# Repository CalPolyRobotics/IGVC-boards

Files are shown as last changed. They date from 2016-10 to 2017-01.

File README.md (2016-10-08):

# IGVC-boards
IGVC schematic and board files

.gitignore is set to only allow uploads of .sch, .brd, and .lib files.

Do not modify folders with "Final" in the name.

Pro tips:

1. Clone this repository to your computer. You need git.

2. In Eagle, go to Options > Directories.

3. Click in the "Projects" text field and then the "Browse" button to choose a directory.

4. Select the "IGVC-boards" directory that you cloned from git.

5. Click "OK" and you should see the directory in the "Projects" list in Eagle Control Panel.

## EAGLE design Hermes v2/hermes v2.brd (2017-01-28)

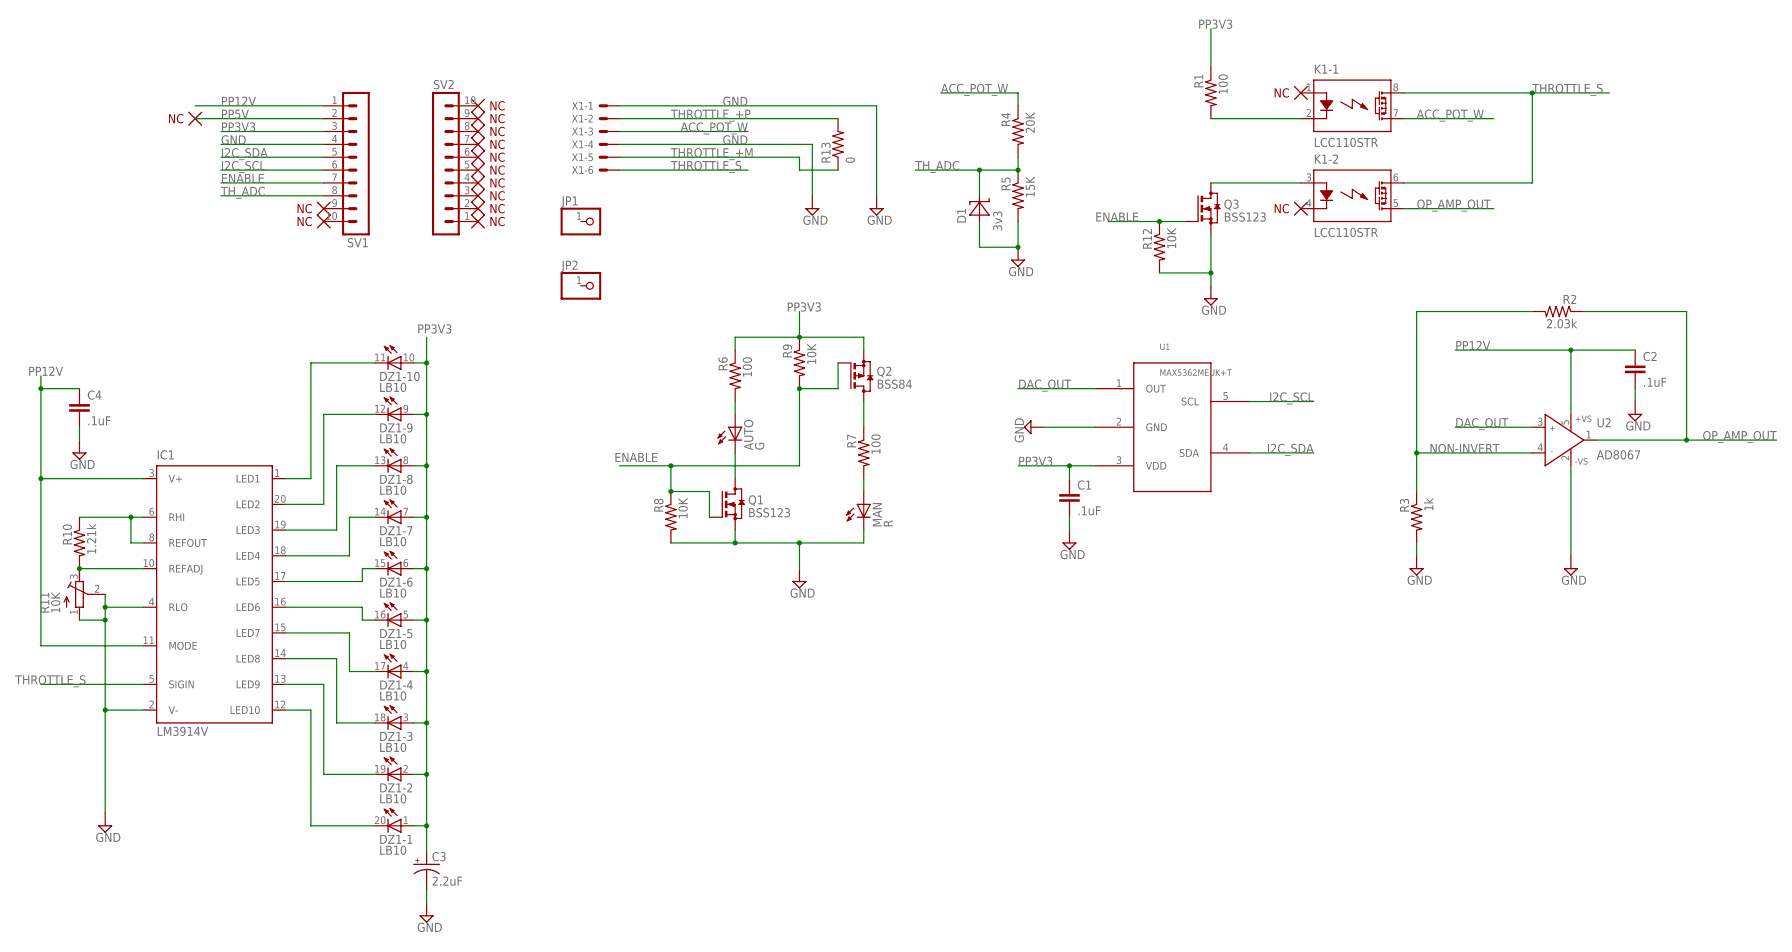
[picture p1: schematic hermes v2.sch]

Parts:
AUTO: G; LED_SML0603
C1, C2, C4: .1uF; C0402
C3: 2.2uF; SMC_A; DIGI 478-3119-2-ND
D1: 3v3; SOD323_ST
DZ1: LB10
IC1: LM3914V; PLCC20S
JP1, JP2: PINHD-1X1; 1X01
K1: LCC110STR; DIL08SMD
MAN: R; LED_SML0603
Q1, Q3: BSS123; SOT23
Q2: BSS84; SOT23
R1, R6, R7: 100; R0603
R2: 2.03k; R0603
R3: 1k; R0603
R4: 20K; R0603
R5: 15K; R0603
R8, R9, R12: 10K; R0603
R10: 1.21k; R0603
R11: 10K; RTRIM5X; DIGI 490-2678-1-ND
R13: 0; R0402
SV1, SV2: MA10-1
U1: DAC; SOT23-5
U2: AD8067; SOT23-5; DIGI 497-13051-1-ND
X1: 22-23-2061

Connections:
ACC_POT_W: K1.7 (D2), R4.1, X1.3
CONTROL_+: K1.2 (K), R1.2
CONTROL_-: K1.3 (A), Q3.3 (D)
DAC_OUT: U1.1 (OUT), U2.3 (IN+)
ENABLE: Q1.1 (G), Q2.1 (G), Q3.1 (G), R8.1, R9.2, R12.1, SV1.7
GND: C1.2, C2.2, C3.-, C4.2, D1.A, IC1.2 (V-), IC1.4 (RLO), MAN.C, Q1.2 (S), Q3.2 (S), R3.2, R5.2, R8.2, R11.1 (A), R11.2 (S), R12.2, SV1.4, U1.2 (GND), U2.2 (-VS), X1.1, X1.4
I2C_SCL: SV1.6, U1.5 (SCL)
I2C_SDA: SV1.5, U1.4 (SDA)
unnamed: DZ1.11 (C), IC1.1 (LED1)
unnamed: AUTO.C, Q1.3 (D)
unnamed: MAN.A, R7.2
unnamed: AUTO.A, R6.2
unnamed: Q2.3 (D), R7.1
unnamed: DZ1.12 (C), IC1.20 (LED2)
unnamed: DZ1.13 (C), IC1.19 (LED3)
unnamed: DZ1.14 (C), IC1.18 (LED4)
unnamed: DZ1.15 (C), IC1.17 (LED5)
unnamed: DZ1.16 (C), IC1.16 (LED6)
unnamed: DZ1.17 (C), IC1.15 (LED7)
unnamed: DZ1.18 (C), IC1.14 (LED8)
unnamed: DZ1.19 (C), IC1.13 (LED9)
unnamed: DZ1.20 (C), IC1.12 (LED10)
unnamed: IC1.10 (REFADJ), R10.2, R11.3 (E)
unnamed: IC1.6 (RHI), IC1.8 (REFOUT), R10.1
NON-INVERT: R2.2, R3.1, U2.4 (IN-)
OP_AMP_OUT: K1.5 (D2), R2.1, U2.1 (OUT)
PP3V3: C1.1, C3.+, DZ1.1 (A), DZ1.2 (A), DZ1.3 (A), DZ1.4 (A), DZ1.5 (A), DZ1.6 (A), DZ1.7 (A), DZ1.8 (A), DZ1.9 (A), DZ1.10 (A), Q2.2 (S), R1.1, R6.1, R9.1, SV1.3, U1.3 (VDD)
PP5V: SV1.2
PP12V: C2.1, C4.1, IC1.3 (V+), IC1.11 (MODE), SV1.1, U2.5 (+VS)
THROTTLE_+M: R13.1, X1.5
THROTTLE_+P: R13.2, X1.2
THROTTLE_S: IC1.5 (SIGIN), K1.6 (D1), K1.8 (D1), X1.6
TH_ADC: D1.C, R4.2, R5.1, SV1.8

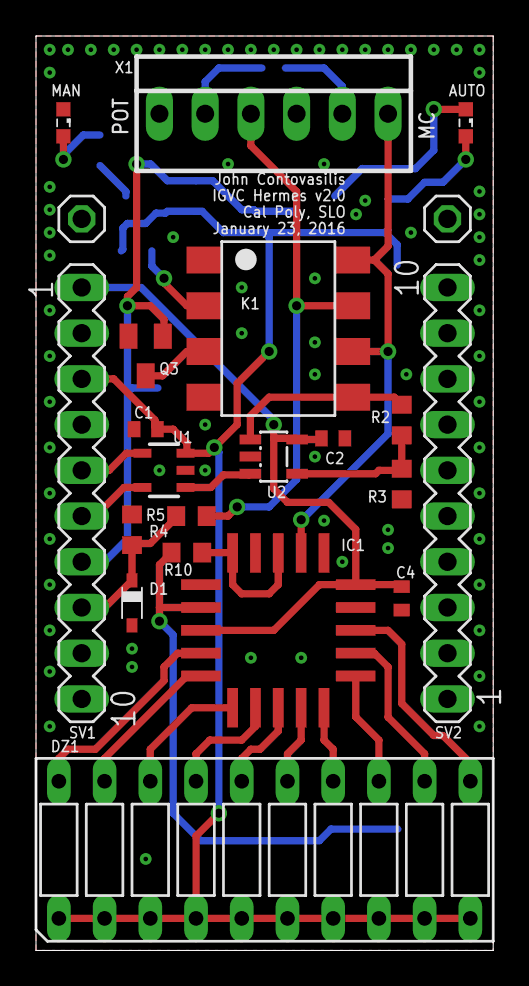
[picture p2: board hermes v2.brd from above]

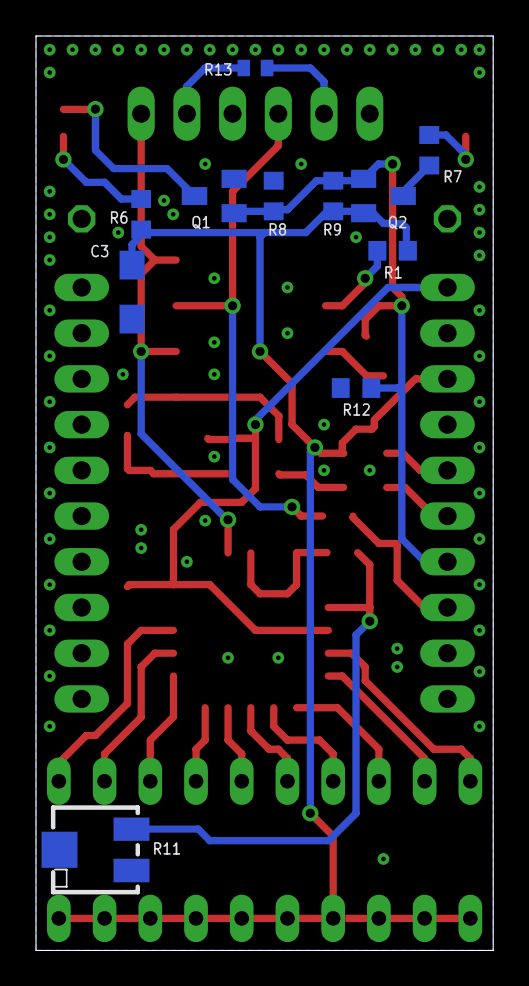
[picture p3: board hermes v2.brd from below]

Board: 2 copper layers, 25.4 x 50.8 mm, 33 parts (11 on the bottom side), 32 nets.

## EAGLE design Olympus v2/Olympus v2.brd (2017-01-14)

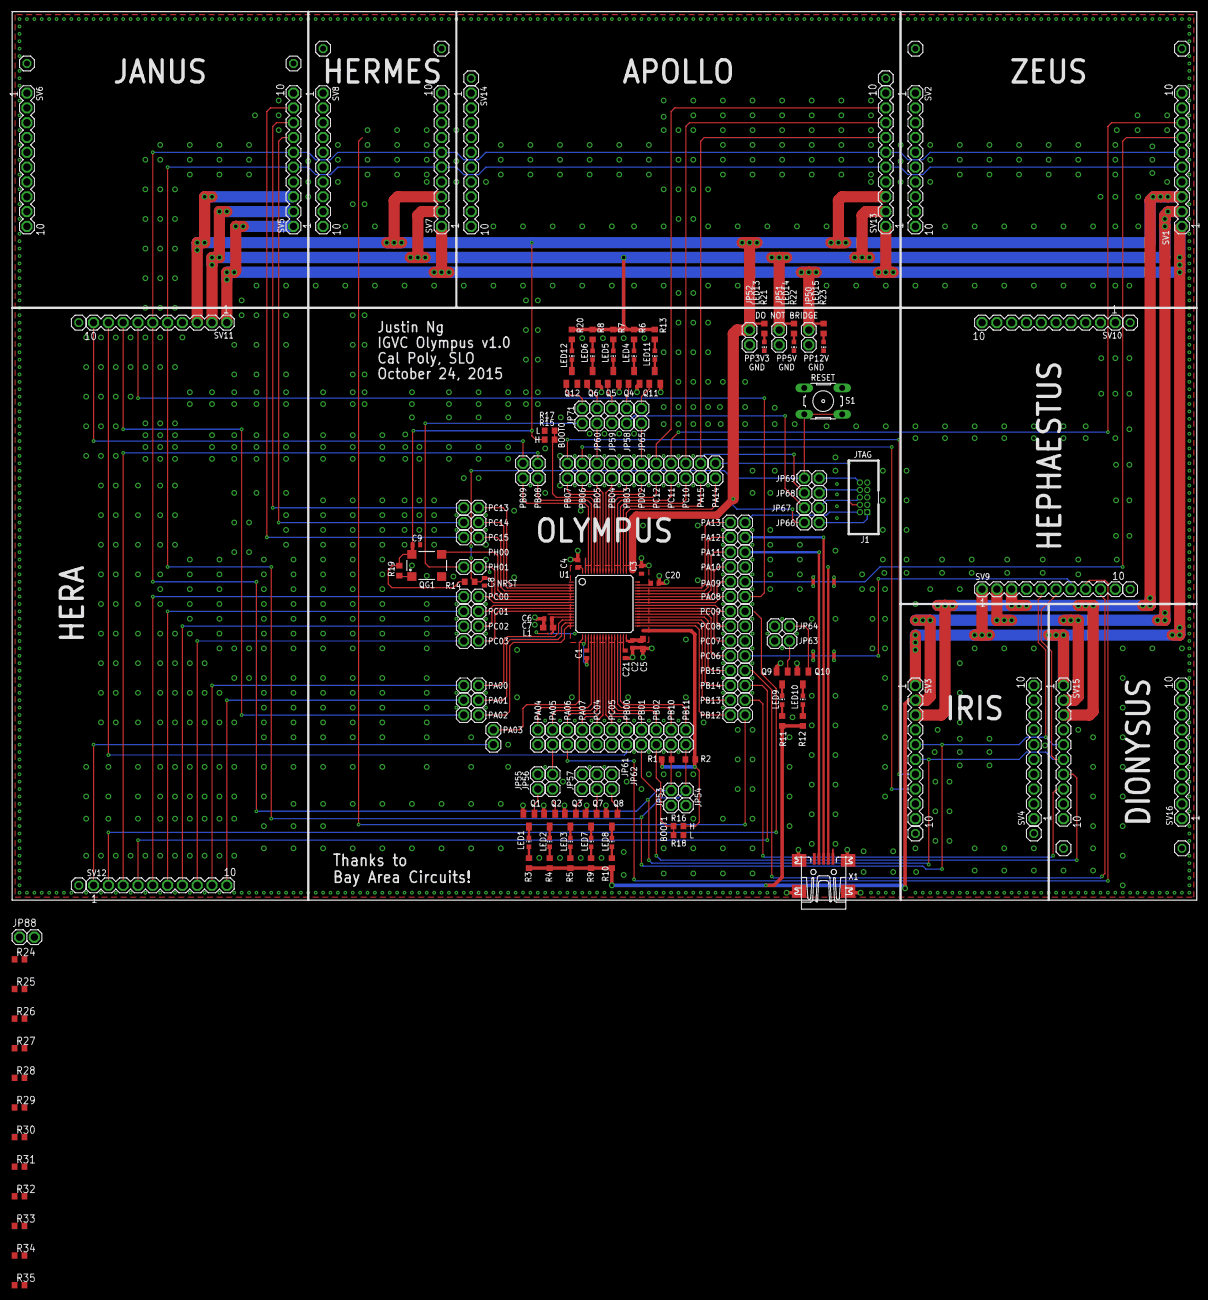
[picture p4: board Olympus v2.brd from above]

Board: 2 copper layers, 203.2 x 152.4 mm, 183 parts (0 on the bottom side), 144 nets.

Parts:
C1, C2, C3, C4, C6, C8, C9: 0.1uF; C0402
C5: 4.7uF; C0603
C7: 1uF; C0603
C20, C21: 2.2uF; C0402
J1: HEADER_10P_0.05
JP1, JP2, JP3, JP4, JP5, JP6, JP7, JP8, JP9, JP10, JP11, JP12, JP13, JP14, JP15, JP16, JP17, JP18, JP19, JP20, JP21, JP22, JP23, JP24, JP25, JP26, JP27, JP28, JP29, JP30, JP31, JP32, JP33, JP34, JP35, JP36, JP37, JP38, JP39, JP40, JP41, JP42, JP43, JP44, JP45, JP46, JP47, JP48, JP49, JP50, JP51, JP52, JP53, JP54, JP55, JP56, JP57, JP58, JP59, JP60, JP61, JP62, JP63, JP64, JP65, JP66, JP67, JP68, JP69, JP70, JP71, JP88: 1X02
JP72, JP73, JP74, JP75, JP76, JP77, JP78, JP79, JP80, JP81, JP82, JP83, JP84, JP85, JP86, JP87: 1X01
L1: L0201
LED1, LED2, LED3, LED4, LED5, LED6, LED7, LED8, LED9, LED10, LED11, LED12, LED13, LED14, LED15: CHIP-LED0603
Q1, Q2, Q3, Q4, Q5, Q6, Q7, Q8, Q9, Q10, Q11, Q12: BSS138; SOT23
QG1: KC7050A20.0000C3GE00; SM77H
R1, R2: 3.3k; R0603
R3, R4, R5, R6, R7, R8, R9, R10, R11, R12, R13, R20: 1k; R0603
R14, R15, R16, R17, R18, R19, R24, R25, R26, R27, R28, R29, R30, R31, R32, R33, R34, R35: 10k; R0603
R21: 82; R0603
R22: 200; R0603
R23: 680; R0603
S1: B3F-10XX
SV1, SV2, SV3, SV4, SV5, SV6, SV7, SV8, SV9, SV10, SV11, SV12, SV13, SV14, SV15, SV16: MA10-1
U1: STM32F205RGT6; LQFP-ST-64-2
X1: MINI-USB-UX60-MB-5ST; UX60-MB-5ST

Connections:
APOLLO_SPI_MOSI: JP45.2, SV13.9
APOLLO_SPI_SCK: JP43.2, SV13.8
APOLLO_SPI_SS_N: JP16.1, JP68.2, SV13.7
DIONYSUS_BRD_EN: JP18.1, SV15.7
DIONYSUS_GPIO: JP30.1, SV15.8
GND: C1.2, C2.2, C3.2, C4.2, C5.2, C6.2, C7.2, C8.2, C9.2, C20.2, C21.2, J1.3, J1.5, JP50.2, JP51.2, JP52.2, JP53.2, JP54.2, LED13.C, LED14.C, LED15.C, Q1.2, Q2.2, Q3.2, Q4.2, Q5.2, Q6.2, Q7.2, Q8.2, Q9.2, Q10.2, Q11.2, Q12.2, QG1.2, R17.1, R18.1, R24.2, R25.2, R26.2, R27.2, R28.2, R29.2, R30.2, R31.2, R32.2, R33.2, R34.2, R35.2, S1.3, S1.4, SV1.4, SV3.4, SV5.4, SV7.4, SV9.4, SV11.4, SV13.4, SV15.4, U1.12, U1.18, U1.63, X1.5
HEPHAESTUS_DIR: JP39.2, SV9.7
HEPHAESTUS_GPIO: JP32.1, SV9.9
HEPHAESTUS_SPD: JP7.1, SV9.8
HERA_HALL1: JP25.1, SV12.3
HERA_HALL2: JP31.1, JP42.2, SV12.4
HERA_SONAR1: JP9.1, SV11.7
HERA_SONAR2: JP3.1, SV11.8
HERA_SONAR3: JP17.1, SV11.9
HERA_SONAR4: JP26.1, SV11.10
HERA_SONAR5: JP4.1, SV12.1
HERA_STEER: JP33.2, SV12.5
HERA_TEMP1: JP34.2, SV12.6
HERA_TEMP2: JP35.2, SV12.7
HERA_TEMP3: JP36.2, SV12.8
HERA_TEMP4: JP1.1, SV12.9
HERA_TEMP5: JP2.1, SV12.10
I2C_SCL: JP27.1, JP53.1, R1.1, SV1.6, SV3.6, SV5.6, SV7.6, SV9.6, SV11.6, SV13.6, SV15.6
I2C_SDA: JP28.1, JP54.1, R2.1, SV1.5, SV3.5, SV5.5, SV7.5, SV9.5, SV11.5, SV13.5, SV15.5
IRIS_UART_RX: JP24.1, SV3.7
IRIS_UART_TX: JP23.1, SV3.8
JANUS_AUTOMAN: JP48.2, SV5.9
JANUS_F: JP47.2, SV5.7
JANUS_R: JP46.2, SV5.8
JTAG_NRST: J1.10, JP69.1
JTAG_SWO: J1.6, JP67.1
JTAG_TDI: J1.8, JP68.1
JTAG_VREF: J1.1, JP66.2
LED1_A: LED1.A, R3.1
LED1_C: LED1.C, Q1.3
LED1_G: JP55.1, Q1.1, R24.1
LED2_A: LED2.A, R4.1
LED2_C: LED2.C, Q2.3
LED2_G: JP56.1, Q2.1, R25.1
LED3_A: LED3.A, R5.1
LED3_C: LED3.C, Q3.3
LED3_G: JP57.1, Q3.1, R26.1
LED4_A: LED4.A, R6.1
LED4_C: LED4.C, Q4.3
LED4_G: JP58.1, Q4.1, R27.1
LED5_A: LED5.A, R7.1
LED5_C: LED5.C, Q5.3
LED5_G: JP59.1, Q5.1, R32.1
LED6_A: LED6.A, R8.1
LED6_C: LED6.C, Q6.3
LED6_G: JP60.1, Q6.1, R33.1
LED7_A: LED7.A, R9.1
LED7_C: LED7.C, Q7.3
LED7_G: JP61.1, Q7.1, R34.1
LED8_A: LED8.A, R10.1
LED8_C: LED8.C, Q8.3
LED8_G: JP62.1, Q8.1, R35.1
LED9_A: LED9.A, R11.1
LED9_C: LED9.C, Q9.3
LED9_G: JP63.1, Q9.1, R28.1
LED10_A: LED10.A, R12.1
LED10_C: LED10.C, Q10.3
LED10_G: JP64.1, Q10.1, R29.1
LED11_A: LED11.A, R13.1
LED11_C: LED11.C, Q11.3
LED11_G: JP65.1, Q11.1, R30.1
LED12_A: LED12.A, R20.1
LED12_C: LED12.C, Q12.3
LED12_G: JP71.1, Q12.1, R31.1
LED13_R: LED13.A, R21.1
LED14_R: LED14.A, R22.1
LED15_R: LED15.A, R23.1
MCU_BOOT0: JP88.1, R15.1, R17.2, U1.60
MCU_BOOT1: JP19.1, R16.1, R18.2
MCU_NRST: C8.1, JP69.2, R14.1, S1.1, S1.2, U1.7
MCU_PA0: JP1.2, U1.14
MCU_PA1: JP2.2, U1.15
MCU_PA2: JP3.2, U1.16
MCU_PA3: JP4.2, U1.17
MCU_PA4: JP5.2, U1.20
MCU_PA5: JP6.2, U1.21
MCU_PA6: JP7.2, U1.22
MCU_PA7: JP8.2, U1.23
MCU_PA8: JP9.2, U1.41
MCU_PA9: JP10.2, U1.42
MCU_PA10: JP11.2, U1.43
MCU_PA11: JP12.2, U1.44
MCU_PA12: JP13.2, U1.45
MCU_PA13: JP14.2, U1.46
MCU_PA14: JP15.2, U1.49
MCU_PA15: JP16.2, U1.50
MCU_PB0: JP17.2, U1.26
MCU_PB1: JP18.2, U1.27
MCU_PB2: JP19.2, U1.28
MCU_PB3: JP20.2, U1.55
MCU_PB4: JP21.2, U1.56
MCU_PB5: JP22.2, U1.57
MCU_PB6: JP23.2, U1.58
MCU_PB7: JP24.2, U1.59
MCU_PB8: JP25.2, U1.61
MCU_PB9: JP26.2, U1.62
MCU_PB10: JP27.2, U1.29
MCU_PB11: JP28.2, U1.30
MCU_PB12: JP29.2, U1.33
MCU_PB13: JP30.2, U1.34
MCU_PB14: JP31.2, U1.35
MCU_PB15: JP32.2, U1.36
MCU_PC0: JP33.1, U1.8
MCU_PC1: JP34.1, U1.9
MCU_PC2: JP35.1, U1.10
MCU_PC3: JP36.1, U1.11
MCU_PC4: JP37.1, U1.24
MCU_PC5: JP38.1, U1.25
MCU_PC6: JP39.1, U1.37
MCU_PC7: JP40.1, U1.38
MCU_PC8: JP41.1, U1.39
MCU_PC9: JP42.1, U1.40
MCU_PC10: JP43.1, U1.51
MCU_PC11: JP44.1, U1.52
MCU_PC12: JP45.1, U1.53
MCU_PC13: JP46.1, U1.2
MCU_PC14: JP47.1, U1.3
MCU_PC15: JP48.1, U1.4
MCU_PD2: JP49.1, U1.54
MCU_PH0: QG1.3, U1.5
MCU_PH1: JP70.1, U1.6
MCU_VCAP_1: C21.1, U1.31
MCU_VCAP_2: C20.1, U1.47
OLYMPUS_GPIO2: JP6.1, JP56.2
OLYMPUS_GPIO4: JP58.2, JP67.2
OLYMPUS_GPIO6: JP22.1, JP60.2
OLYMPUS_GPIO11: JP49.2, JP65.2
OLYMPUS_GPIO12: JP70.2, JP71.2
OLYMPUS_SWDCLK: J1.4, JP15.1
OLYMPUS_SWDIO: J1.2, JP14.1
OLYMPUS_USBDN: JP12.1, X1.2
OLYMPUS_USBDP: JP13.1, X1.3
OSC_EN: QG1.1, R19.1
PP3V3: C1.1, C2.1, C3.1, C4.1, C5.1, C9.1, JP52.1, JP66.1, L1.2, QG1.4, R1.2, R2.2, R14.2, R15.2, R16.2, R19.2, R21.2, SV1.3, SV3.3, SV5.3, SV7.3, SV9.3, SV11.3, SV13.3, SV15.3, U1.19, U1.32, U1.48, U1.64
PP3V3A: C6.1, C7.1, L1.1, U1.13
PP5V: JP51.1, R3.2, R4.2, R5.2, R6.2, R7.2, R8.2, R9.2, R10.2, R11.2, R12.2, R13.2, R20.2, R22.2, SV1.2, SV3.2, SV5.2, SV7.2, SV9.2, SV11.2, SV13.2, SV15.2
PP12V: JP50.1, R23.2, SV1.1, SV3.1, SV5.1, SV7.1, SV9.1, SV11.1, SV13.1, SV15.1
ZEUS_GPIO: JP44.2, SV1.8
ZEUS_SHUTDOWN_N: JP10.1, SV1.7

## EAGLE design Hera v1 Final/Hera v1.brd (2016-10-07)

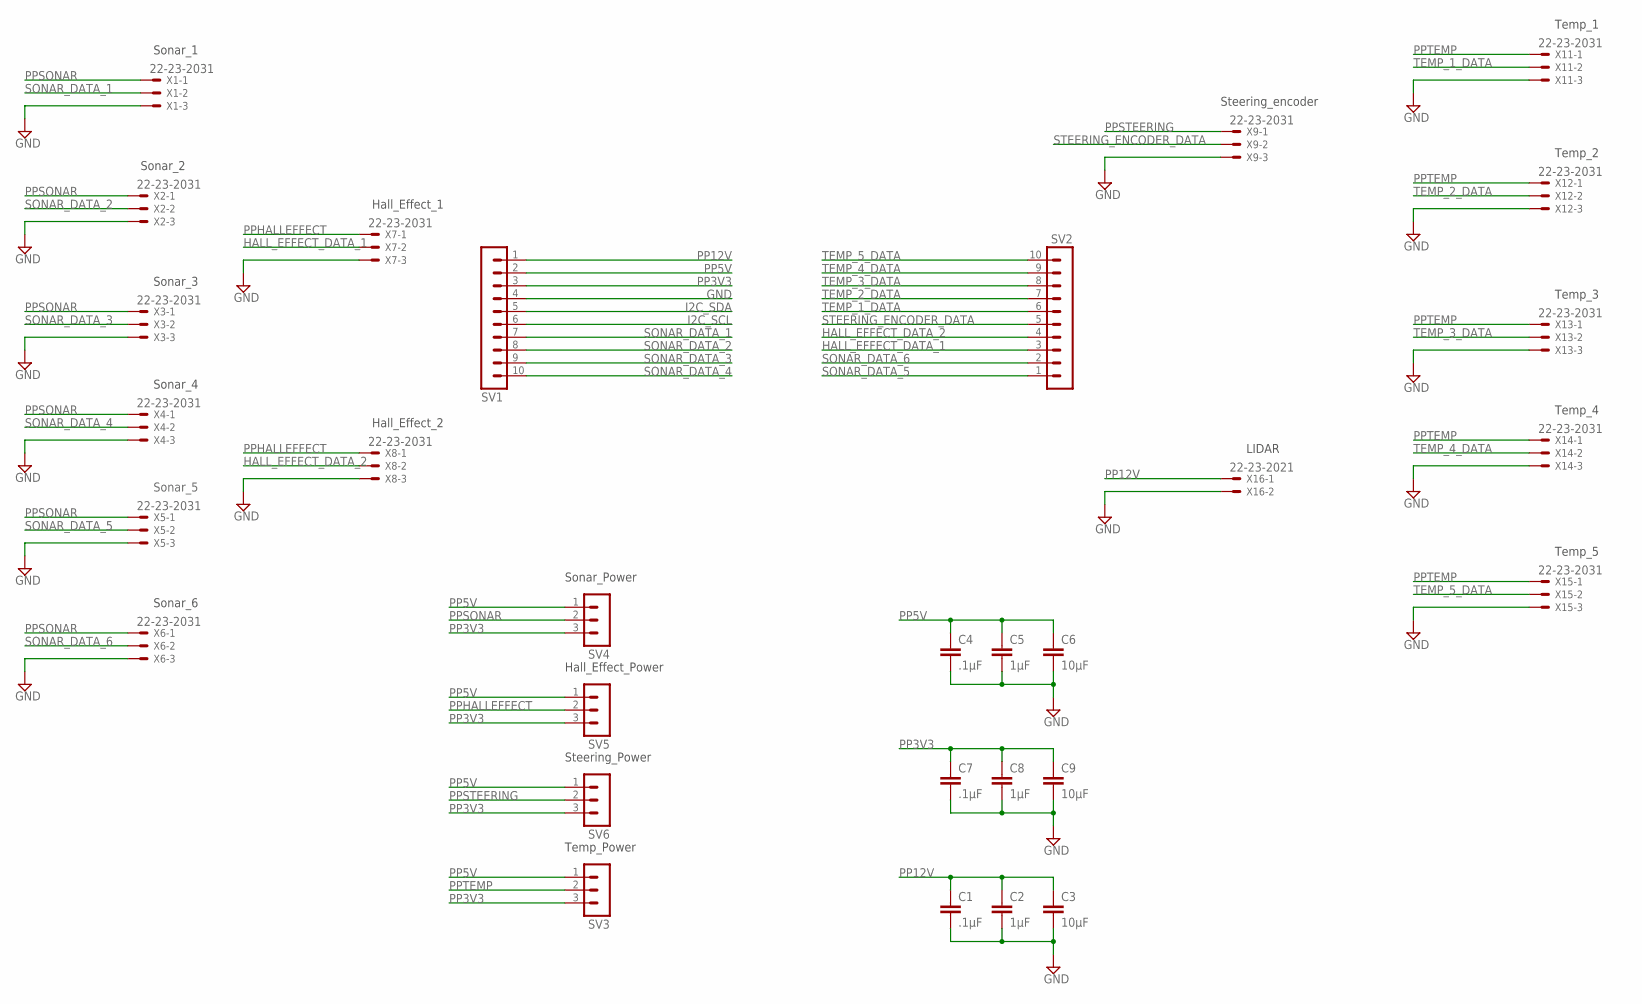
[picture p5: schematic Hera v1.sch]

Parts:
C1, C4, C7: .1µF; C0402; DIGI 490-5920-1-ND
C2, C5, C8: 1µF; C0603; DIGI 490-3897-1-ND
C3, C6, C9: 10µF; C1206; DIGI 490-5525-1-ND
SV1, SV2: MA10-1
SV3, SV4, SV5, SV6: MA03-1
X1, X2, X3, X4, X5, X6, X7, X8, X9, X11, X12, X13, X14, X15: 22-23-2031
X16: 22-23-2021

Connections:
GND: C1.2, C2.2, C3.2, C4.2, C5.2, C6.2, C7.2, C8.2, C9.2, SV1.4, X1.3, X2.3, X3.3, X4.3, X5.3, X6.3, X7.3, X8.3, X9.3, X11.3, X12.3, X13.3, X14.3, X15.3, X16.2
HALL_EFFECT_DATA_1: SV2.3, X7.2
HALL_EFFECT_DATA_2: SV2.4, X8.2
I2C_SCL: SV1.6
I2C_SDA: SV1.5
PP3V3: C7.1, C8.1, C9.1, SV1.3, SV3.3, SV4.3, SV5.3, SV6.3
PP5V: C4.1, C5.1, C6.1, SV1.2, SV3.1, SV4.1, SV5.1, SV6.1
PP12V: C1.1, C2.1, C3.1, SV1.1, X16.1
PPHALLEFFECT: SV5.2, X7.1, X8.1
PPSONAR: SV4.2, X1.1, X2.1, X3.1, X4.1, X5.1, X6.1
PPSTEERING: SV6.2, X9.1
PPTEMP: SV3.2, X11.1, X12.1, X13.1, X14.1, X15.1
SONAR_DATA_1: SV1.7, X1.2
SONAR_DATA_2: SV1.8, X2.2
SONAR_DATA_3: SV1.9, X3.2
SONAR_DATA_4: SV1.10, X4.2
SONAR_DATA_5: SV2.1, X5.2
SONAR_DATA_6: SV2.2, X6.2
STEERING_ENCODER_DATA: SV2.5, X9.2
TEMP_1_DATA: SV2.6, X11.2
TEMP_2_DATA: SV2.7, X12.2
TEMP_3_DATA: SV2.8, X13.2
TEMP_4_DATA: SV2.9, X14.2
TEMP_5_DATA: SV2.10, X15.2

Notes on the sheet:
Sonar_1
Sonar_2
Sonar_3
Sonar_4
Sonar_5
Sonar_6
Hall_Effect_1
Hall_Effect_2
Steering_encoder
Temp_1
Temp_2
Temp_3
Temp_4
Temp_5
LIDAR
Sonar_Power
Hall_Effect_Power
Steering_Power
Temp_Power

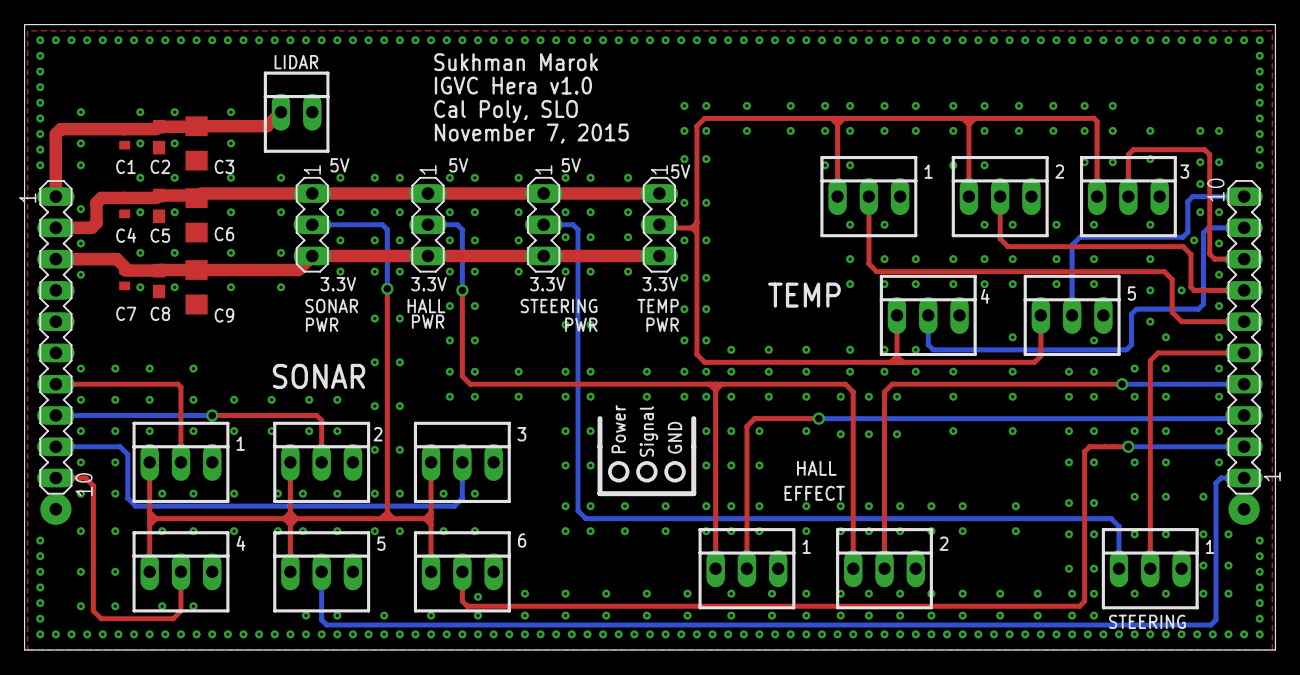
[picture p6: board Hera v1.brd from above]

Board: 2 copper layers, 101.6 x 50.8 mm, 30 parts (0 on the bottom side), 22 nets.

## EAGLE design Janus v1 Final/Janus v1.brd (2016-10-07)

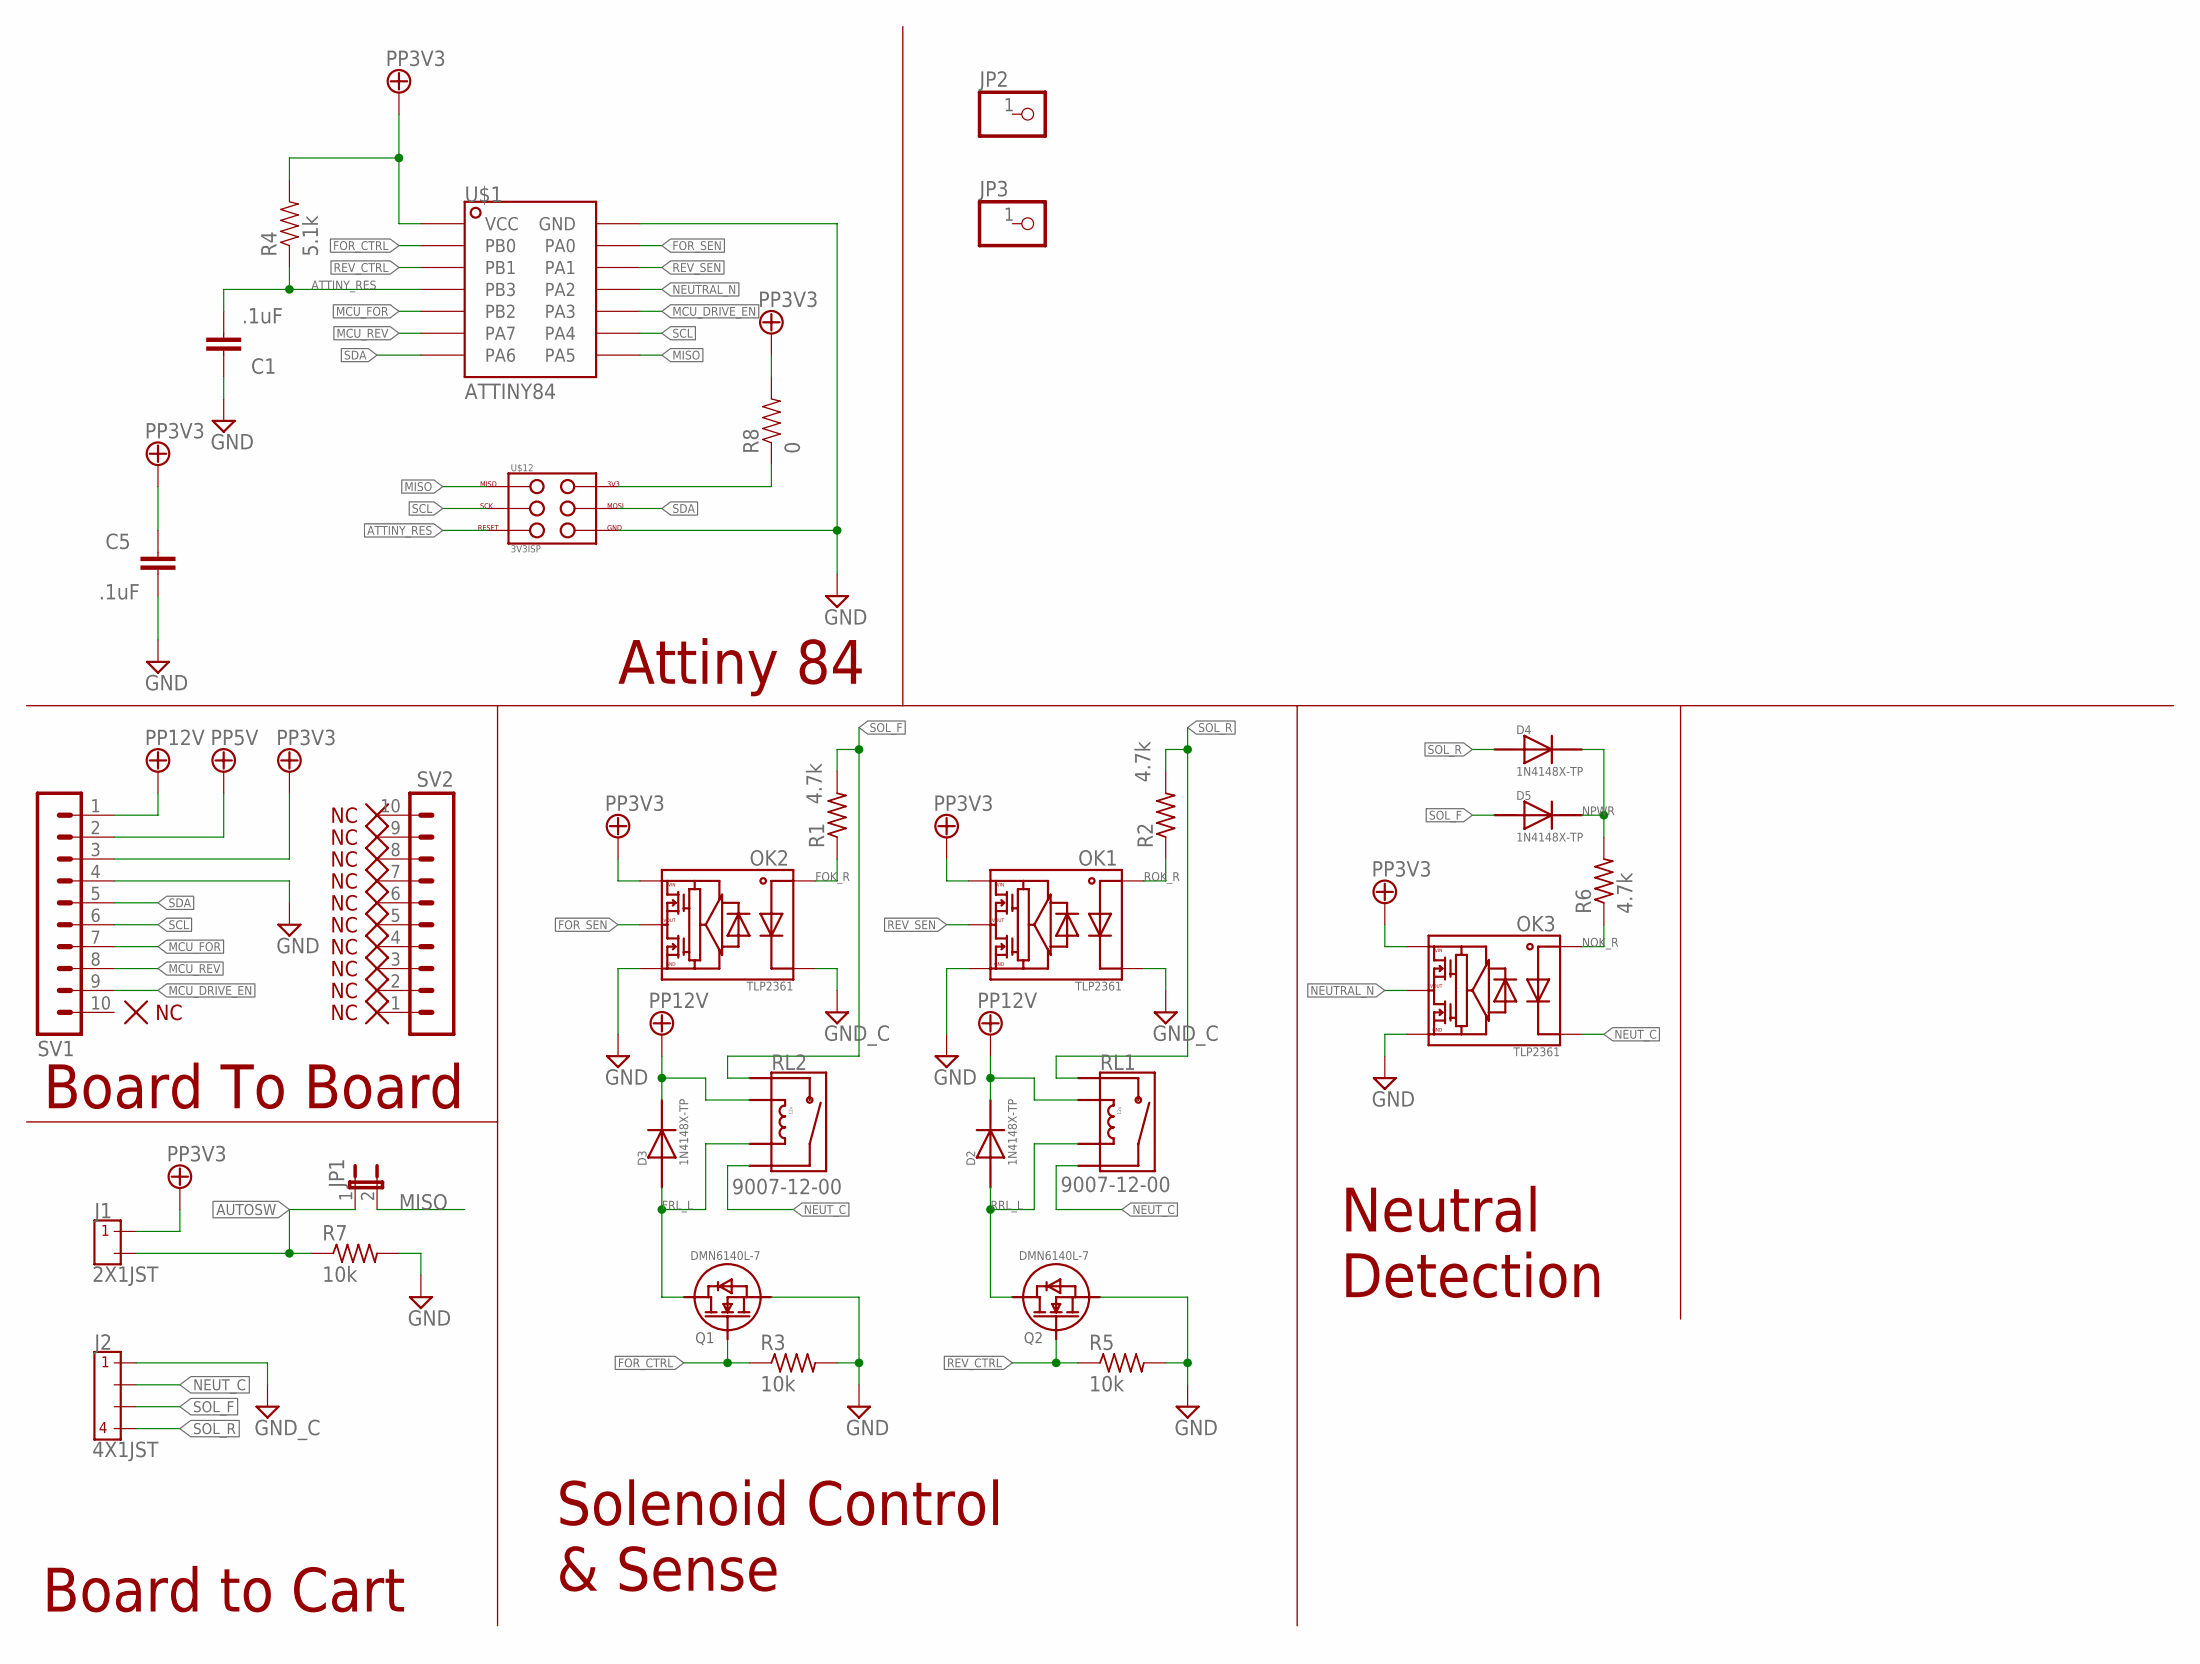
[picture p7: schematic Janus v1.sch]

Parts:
C1, C5: .1uF; C0603
D2, D3, D4, D5: 1N4148X-TP; SOD523_SC79
J1: 2X1JST; JST-2-PTH-VERT
J2: 4X1JST; JST-4-PTH-VERT
JP1: JP1E; JP1
JP2, JP3: PINHD-1X1; 1X01
OK1, OK2, OK3: TLP2361; SOIC-6-5
Q1, Q2: DMN6140L-7; SOT-23-3
R1, R2, R6: 4.7k; R0805
R3, R5, R7: 10k; R0603
R4: 5.1k; 0603-RES
R8: 0; 0603-RES
RL1, RL2: 9007-12-00; RELAY9007
SV1, SV2: MA10-1
U$1: ATTINY84; SOIC-14
U$12: 3V3ISP; 3X2SMD

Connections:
ATTINY_RES: C1.2, R4.1, U$1.P$4 (PB3), U$12.P$3
AUTOSW: J1.2, JP1.1, R7.1
FOK_R: OK2.P$1, R1.1
FOR_CTRL: Q1.P$1 (G), R3.1, U$1.P$2 (PB0)
FOR_SEN: OK2.P$5, U$1.P$13 (PA0)
FRL_L: D3.P$1, Q1.P$3 (D), RL2.P$3 (COILB)
GND: C1.1, C5.2, OK1.P$4, OK2.P$4, OK3.P$4, Q1.P$2 (S), Q2.P$2 (S), R3.2, R5.2, R7.2, SV1.4, U$1.P$14 (GND), U$12.P$4
GND_1: J2.1, OK1.P$3, OK2.P$3
MCU_DRIVE_EN: SV1.9, U$1.P$10 (PA3)
MCU_FOR: SV1.7, U$1.P$5 (PB2)
MCU_REV: SV1.8, U$1.P$6 (PA7)
MISO: JP1.2, U$1.P$8 (PA5), U$12.P$1
unnamed: R8.1, U$12.P$6
NEUTRAL_N: OK3.P$5, U$1.P$11 (PA2)
NEUT_C: J2.2, OK3.P$3, RL1.P$4 (SIGB), RL2.P$4 (SIGB)
NOK_R: OK3.P$1, R6.1
NPWR: D4.P$2, D5.P$2, R6.2
PP3V3: C5.1, J1.1, OK1.P$6, OK2.P$6, OK3.P$6, R4.2, R8.2, SV1.3, U$1.P$1 (VCC)
PP5V: SV1.2
PP12V: D2.P$2, D3.P$2, RL1.P$2 (COILA), RL2.P$2 (COILA), SV1.1
REV_CTRL: Q2.P$1 (G), R5.1, U$1.P$3 (PB1)
REV_SEN: OK1.P$5, U$1.P$12 (PA1)
ROK_R: OK1.P$1, R2.1
RRL_L: D2.P$1, Q2.P$3 (D), RL1.P$3 (COILB)
SCL: SV1.6, U$1.P$9 (PA4), U$12.P$2
SDA: SV1.5, U$1.P$7 (PA6), U$12.P$5
SOL_F: D5.P$1, J2.3, R1.2, RL2.P$1 (SIGA)
SOL_R: D4.P$1, J2.4, R2.2, RL1.P$1 (SIGA)

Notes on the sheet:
Attiny 84
Solenoid Control & Sense
Board To Board
Board to Cart
Neutral Detection

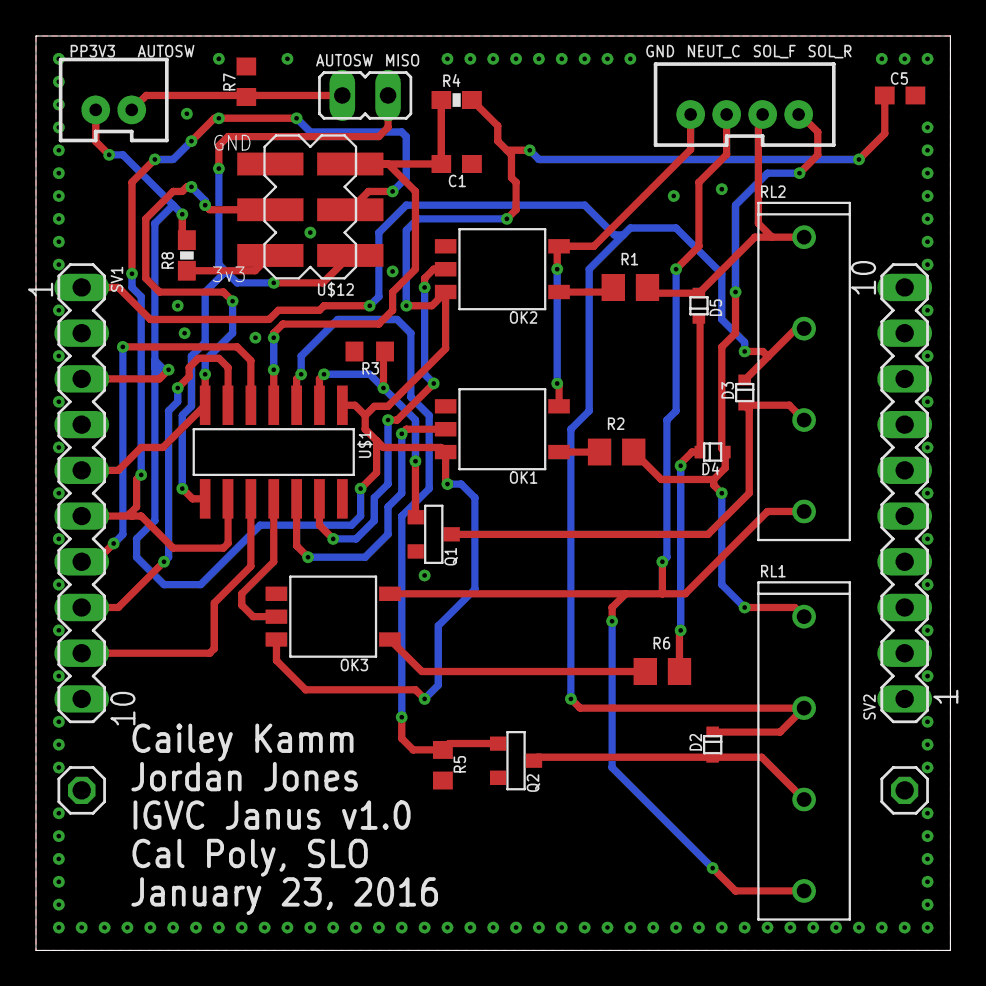
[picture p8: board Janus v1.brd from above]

Board: 2 copper layers, 50.8 x 50.8 mm, 30 parts (0 on the bottom side), 27 nets.

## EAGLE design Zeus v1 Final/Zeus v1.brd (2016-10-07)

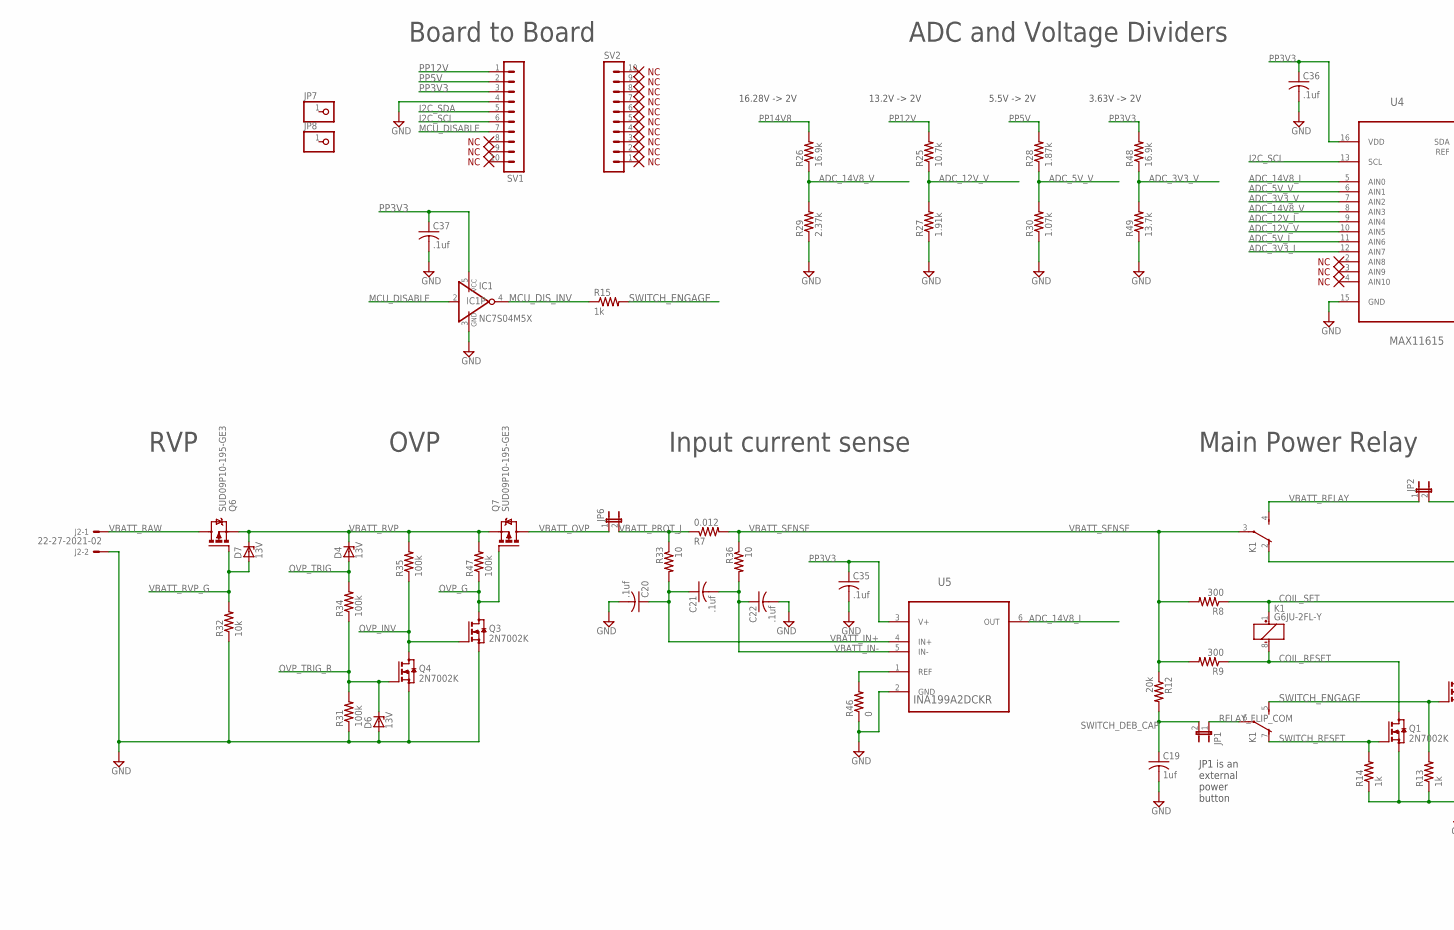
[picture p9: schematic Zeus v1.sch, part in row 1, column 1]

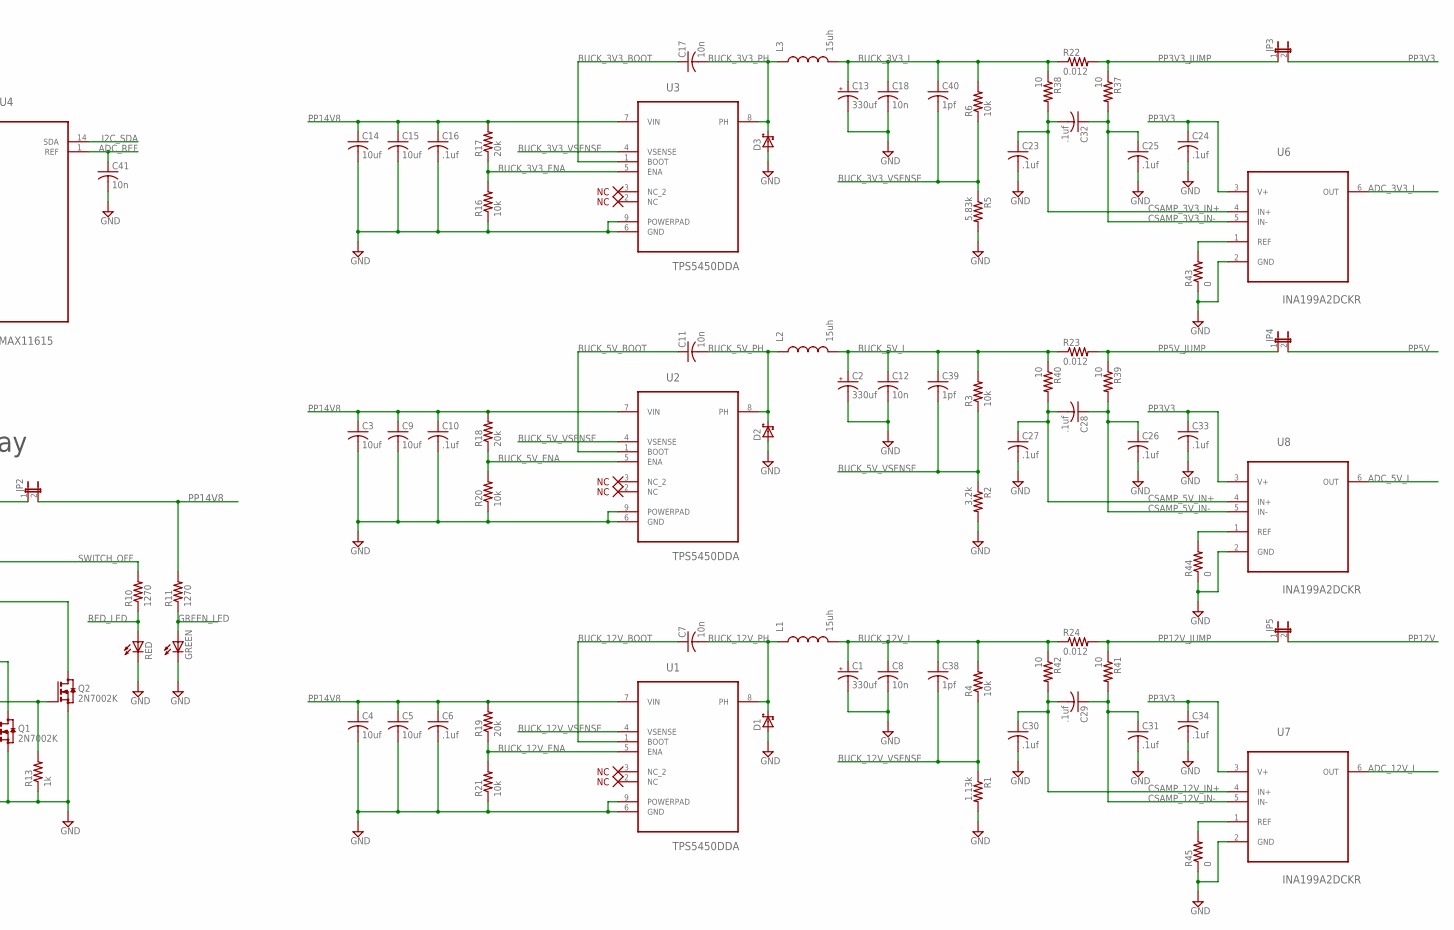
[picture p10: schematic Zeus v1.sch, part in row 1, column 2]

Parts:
C1, C2, C13: 330uf; 153CLV-0605
C3, C4, C5, C9, C14, C15: 10uf; C1206
C6, C10, C16, C20, C21, C22, C23, C24, C25, C26, C27, C28, C29, C30, C31, C32, C33, C34, C35, C36, C37: .1uf; C0402
C7, C8, C11, C12, C17, C18, C41: 10n; C0402
C19: 1uf; C0603
C38, C39, C40: 1pf; C0402
D1, D2, D3: SCHOTTKY-DIODESMC; SMC
D4, D6, D7: 13V; SOT23
GREEN: LED_ESML0603; LED_SML0603
IC1: NC7S04M5X; SOT23-5
J2: 22-27-2021-02; 6410-02
JP1, JP2, JP3, JP4, JP5, JP6: JP1E; JP1
JP7, JP8: PINHD-1X1; 1X01
K1: G6JU-2FL-Y; G6J-2FL-Y
L1, L2, L3: 15uh; SUMIDA
Q1, Q2, Q3, Q4: 2N7002K; SOT23
Q6, Q7: SUD09P10-195-GE3; D-PAK_TO252AA
R1: 1.13k; R0603
R2: 3.2k; R0603
R3, R4, R6, R16, R20, R21, R32: 10k; R0603
R5: 5.83k; R0603
R7, R22, R23, R24: 0.012; R0805
R8, R9: 300; R0603
R10, R11: 1270; R0603
R12, R17, R18, R19: 20k; R0603
R13, R14, R15: 1k; R0603
R25: 10.7k; R0603
R26, R48: 16.9k; R0603
R27: 1.91k; R0603
R28: 1.87k; R0603
R29: 2.37k; R0603
R30: 1.07k; R0603
R31, R34, R35, R47: 100k; R0603
R33, R36, R37, R38, R39, R40, R41, R42: 10; R0603
R43, R44, R45, R46: 0; R0603
R49: 13.7k; R0603
RED: LED_ESML0603; LED_SML0603
SV1, SV2: MA10-1
U1, U2, U3: TPS5450DDA; SOIC127P600X170-9N
U4: MAX11615; SOP63P600X175-16N
U5, U6, U7, U8: INA199A2DCKR; SOT65P210X110-6N

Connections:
ADC_3V3_I: U4.12 (AIN7), U6.6 (OUT)
ADC_3V3_V: R48.1, R49.2, U4.7 (AIN2)
ADC_5V_I: U4.11 (AIN6), U8.6 (OUT)
ADC_5V_V: R28.1, R30.2, U4.6 (AIN1)
ADC_12V_I: U4.9 (AIN4), U7.6 (OUT)
ADC_12V_V: R25.1, R27.2, U4.10 (AIN5)
ADC_14V8_I: U4.5 (AIN0), U5.6 (OUT)
ADC_14V8_V: R26.1, R29.2, U4.8 (AIN3)
ADC_REF: C41.1, U4.1 (REF)
BUCK_3V3_BOOT: C17.1, U3.1 (BOOT)
BUCK_3V3_ENA: R16.2, R17.1, U3.5 (ENA)
BUCK_3V3_L: C13.+, C18.1, C40.1, L3.P$2 (2), R6.2, R22.1, R38.1
BUCK_3V3_PH: C17.2, D3.C, L3.P$1 (1), U3.8 (PH)
BUCK_3V3_VSENSE: C40.2, R5.1, R6.1, U3.4 (VSENSE)
BUCK_5V_BOOT: C11.1, U2.1 (BOOT)
BUCK_5V_ENA: R18.1, R20.2, U2.5 (ENA)
BUCK_5V_L: C2.+, C12.1, C39.1, L2.P$2 (2), R3.2, R23.1, R40.1
BUCK_5V_PH: C11.2, D2.C, L2.P$1 (1), U2.8 (PH)
BUCK_5V_VSENSE: C39.2, R2.1, R3.1, U2.4 (VSENSE)
BUCK_12V_BOOT: C7.1, U1.1 (BOOT)
BUCK_12V_ENA: R19.1, R21.2, U1.5 (ENA)
BUCK_12V_L: C1.+, C8.1, C38.1, L1.P$2 (2), R4.2, R24.1, R42.1
BUCK_12V_PH: C7.2, D1.C, L1.P$1 (1), U1.8 (PH)
BUCK_12V_VSENSE: C38.2, R1.1, R4.1, U1.4 (VSENSE)
COIL_RESET: K1.8 (-), Q1.3 (D), R9.1
COIL_SET: K1.1 (+), Q2.3 (D), R8.1
CSAMP_3V3_IN+: C23.1, C32.2, R38.2, U6.4 (IN+)
CSAMP_3V3_IN-: C25.1, C32.1, R37.2, U6.5 (IN-)
CSAMP_3V3_REF: R43.2, U6.1 (REF)
CSAMP_5V_IN+: C27.1, C28.2, R40.2, U8.4 (IN+)
CSAMP_5V_IN-: C26.1, C28.1, R39.2, U8.5 (IN-)
CSAMP_5V_REF: R44.2, U8.1 (REF)
CSAMP_12V_IN+: C29.2, C30.1, R42.2, U7.4 (IN+)
CSAMP_12V_IN-: C29.1, C31.1, R41.2, U7.5 (IN-)
CSAMP_12V_REF: R45.2, U7.1 (REF)
GND: C1.-, C2.-, C3.2, C4.2, C5.2, C6.2, C8.2, C9.2, C10.2, C12.2, C13.-, C14.2, C15.2, C16.2, C18.2, C19.2, C20.2, C22.2, C23.2, C24.2, C25.2, C26.2, C27.2, C30.2, C31.2, C33.2, C34.2, C35.2, C36.2, C37.2, C41.2, D1.A, D2.A, D3.A, D6.1 (A), GREEN.C, IC1.3 (GND), J2.2, Q1.2 (S), Q2.2 (S), Q3.2 (S), Q4.2 (S), R1.2, R2.2, R5.2, R13.1, R14.1, R16.1, R20.1, R21.1, R27.1, R29.1, R30.1, R31.1, R32.1, R43.1, R44.1, R45.1, R46.1, R49.1, RED.C, SV1.4, U1.6 (GND), U1.9 (POWERPAD), U2.6 (GND), U2.9 (POWERPAD), U3.6 (GND), U3.9 (POWERPAD), U4.15 (GND), U5.2 (GND), U6.2 (GND), U7.2 (GND), U8.2 (GND)
GREEN_LED: GREEN.A, R11.1
I2C_SCL: SV1.6, U4.13 (SCL)
I2C_SDA: SV1.5, U4.14 (SDA)
MCU_DISABLE: IC1.2 (I), SV1.7
MCU_DIS_INV: IC1.4 (O), R15.1
OPAMP_REF1: R46.2, U5.1 (REF)
OVP_G: Q3.3 (D), Q7.1 (G), R47.1
OVP_INV: Q3.1 (G), Q4.3 (D), R35.1
OVP_TRIG: D4.1 (A), R34.2
OVP_TRIG_R: D6.3 (C), Q4.1 (G), R31.2, R34.1
PP3V3: C24.1, C33.1, C34.1, C35.1, C36.1, C37.1, IC1.5 (VCC), JP3.2, R48.2, SV1.3, U4.16 (VDD), U5.3 (V+), U6.3 (V+), U7.3 (V+), U8.3 (V+)
PP3V3_JUMP: JP3.1, R22.2, R37.1
PP5V: JP4.2, R28.2, SV1.2
PP5V_JUMP: JP4.1, R23.2, R39.1
PP12V: JP5.2, R25.2, SV1.1
PP12V_JUMP: JP5.1, R24.2, R41.1
PP14V8: C3.1, C4.1, C5.1, C6.1, C9.1, C10.1, C14.1, C15.1, C16.1, JP2.2, R11.2, R17.2, R18.2, R19.2, R26.2, U1.7 (VIN), U2.7 (VIN), U3.7 (VIN)
RED_LED: R10.1, RED.A
RELAY_FLIP_COM: JP1.1, K1.6
SWITCH_DEB_CAP: C19.1, JP1.2, R12.2
SWITCH_ENGAGE: K1.5 (S), Q2.1 (G), R13.2, R15.2
SWITCH_OFF: K1.2 (O), R10.2
SWITCH_RESET: K1.7 (O), Q1.1 (G), R14.2
VBATT_IN+: C20.1, C21.1, R33.2, U5.4 (IN+)
VBATT_IN-: C21.2, C22.1, R36.2, U5.5 (IN-)
VBATT_OVP: JP6.1, Q7.4 (D)
VBATT_PROT_J: JP6.2, R7.1, R33.1
VBATT_RAW: J2.1, Q6.4 (D)
VBATT_RELAY: JP2.1, K1.4 (S)
VBATT_RVP: D4.3 (C), D7.3 (C), Q6.3 (S), Q7.3 (S), R35.2, R47.2
VBATT_RVP_G: D7.1 (A), Q6.1 (G), R32.2
VBATT_SENSE: K1.3, R7.2, R8.2, R9.2, R12.1, R36.1

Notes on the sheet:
RVP
Input current sense
JP1 is an external power button
Board to Board
Main Power Relay
ADC and Voltage Dividers
16.28V -> 2V
5.5V -> 2V
13.2V -> 2V
OVP
3.63V -> 2V

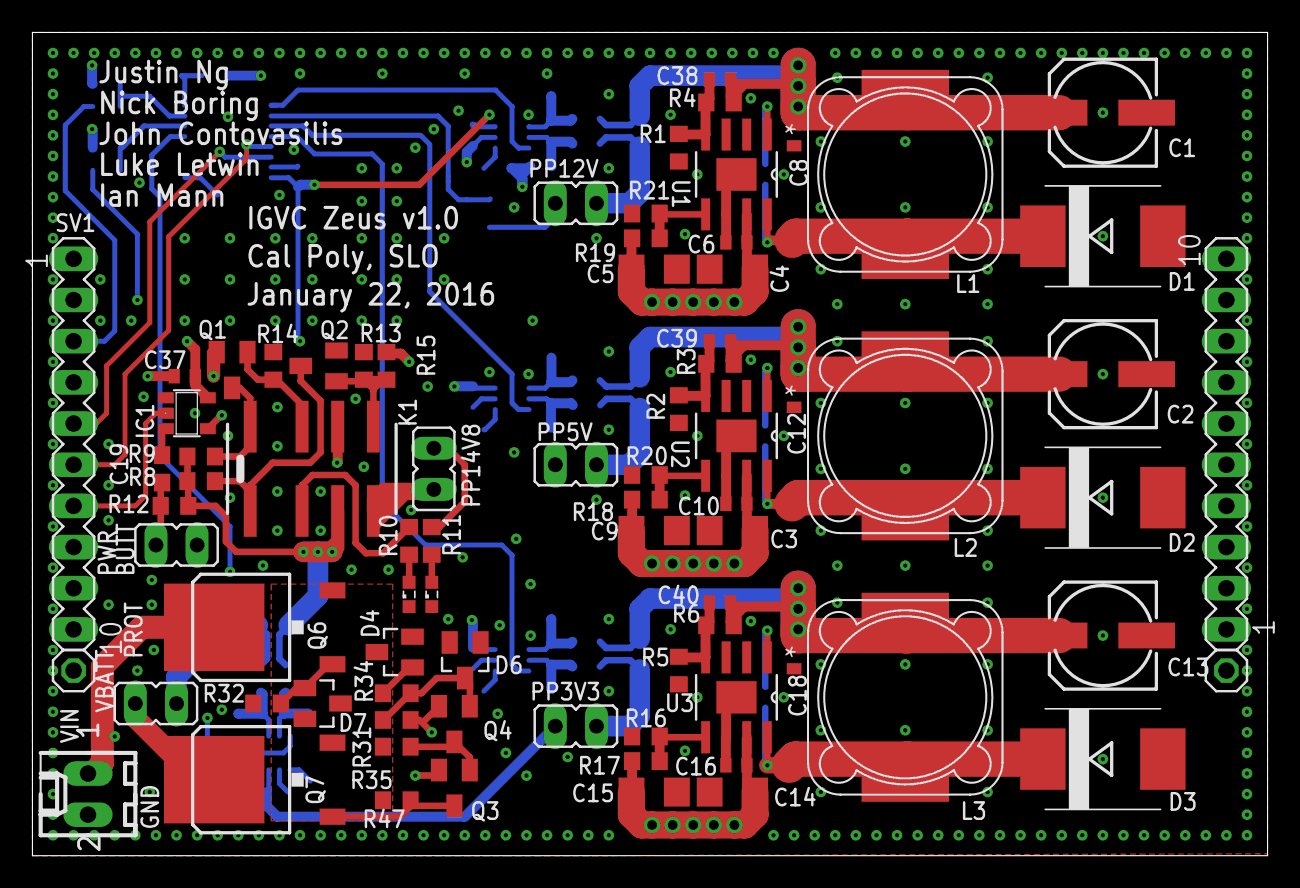
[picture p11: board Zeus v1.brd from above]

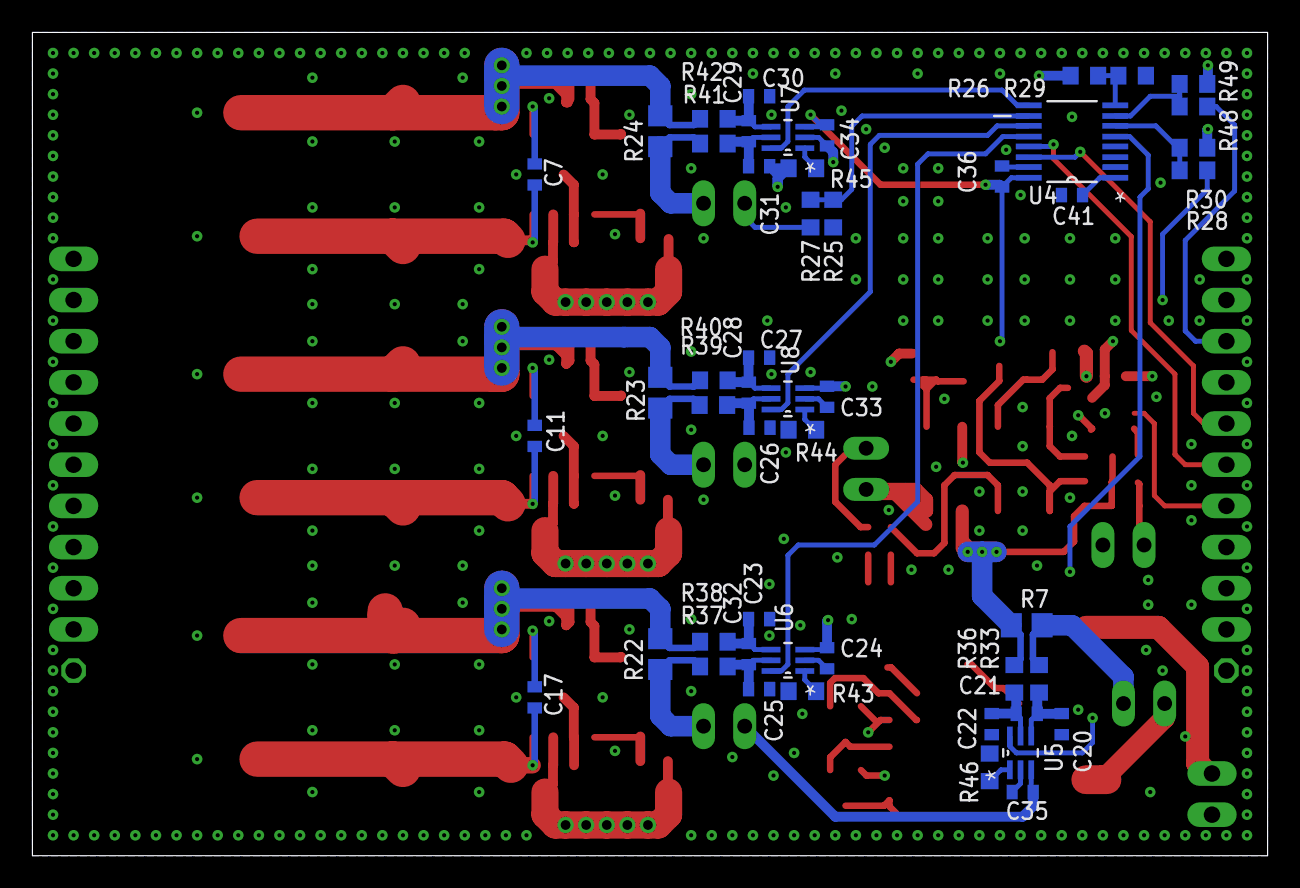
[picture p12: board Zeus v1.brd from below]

Board: 4 copper layers, 76.2 x 50.8 mm, 128 parts (50 on the bottom side), 68 nets.

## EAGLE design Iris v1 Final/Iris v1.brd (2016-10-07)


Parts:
C1, C2, C7: .1uF; C0402
C3: 4.7uF; C0603
C4, C5: 47pF; C0402
C6: 100nF; C0402
IC1: FT230XS; SSOP16; DIGI 768-1135-1-ND
IC2: PCF8574TS; SSOP20; DIGI 568-8246-1-ND
JP1, JP2: PINHD-1X10; 1X10
JP3, JP4: PINHD-1X1; 1X01
JP5: PINHD-1X2; 1X02
R1: 4k7; R0402
R2, R16: 10k; R0402
R3, R4: 27; R0402
R5, R6, R8, R9, R10, R11, R12, R13, R14, R15: 130; R0402
R7: 10k; R0603
RX: LEDCHIP-LED0603; CHIP-LED0603; DIGI 160-1434-1-ND
TX: LEDCHIP-LED0603; CHIP-LED0603; DIGI 160-1434-1-ND
U1: VDMR10.0; VDMR10A0
X1: MINI-USB-UX60-MB-5ST; UX60-MB-5ST; DIGI H2959CT-ND

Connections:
DISP_A: R8.1, U1.7 (A)
DISP_B: R9.1, U1.6 (B)
DISP_C: R10.1, U1.4 (C)
DISP_D: R11.1, U1.2 (D)
DISP_DP: R15.1, U1.5 (DP)
DISP_E: R12.1, U1.1 (E)
DISP_F: R13.1, U1.9 (F)
DISP_G: R14.1, U1.10 (G)
FTDI_DN: IC1.9 (USBDM), R4.1
FTDI_DP: IC1.8 (USBDP), R3.1
GND: C1.2, C2.2, C3.2, C4.2, C5.2, C6.2, C7.2, IC1.5 (GND), IC1.13 (GND), IC2.7 (A1), IC2.9 (A2), IC2.15 (VSS), JP1.4, JP5.2, R2.1, X1.5
GPIO_A0: IC2.6 (A0), JP5.1, R16.1
GPIO_P0: IC2.10 (P0), R12.2
GPIO_P1: IC2.11 (P1), R15.2
GPIO_P2: IC2.12 (P2), R10.2
GPIO_P3: IC2.14 (P3), R11.2
GPIO_P4: IC2.16 (P4), R14.2
GPIO_P5: IC2.17 (P5), R13.2
GPIO_P6: IC2.19 (P6), R8.2
GPIO_P7: IC2.20 (P7), R9.2
I2C_SCL: IC2.2 (SCL), JP1.6
I2C_SDA: IC2.4 (SDA), JP1.5
LED_RX_C: R6.2, RX.C
LED_RX_SINK: IC1.14 (CBUS1), R6.1
LED_TX_C: R5.2, TX.C
LED_TX_SINK: IC1.7 (CBUS2), R5.1
PP3V3: JP1.3, RX.A, TX.A, U1.3 (ANODE), U1.8 (ANODE)
PP3V3_FTDI: C6.1, IC1.3 (VCCIO), IC1.10 (3V3OUT), R7.2
PP5V: C1.1, C2.1, C3.1, C7.1, IC1.12 (VCC), IC2.5 (VDD), JP1.2, R16.2
PP12V: JP1.1
RST: IC1.11 (!RESET), R7.1
USART_RX: IC1.1 (TXD), JP1.7
USART_TX: IC1.4 (RXD), JP1.8
USB_5V: R1.2, X1.1
USB_DN: C5.1, R4.2, X1.2
USB_DP: C4.1, R3.2, X1.3
VBUS_SENSE: IC1.15 (CBUS0), R1.1, R2.2


Board: 2 copper layers, 25.4 x 50.8 mm, 34 parts (1 on the bottom side), 36 nets.

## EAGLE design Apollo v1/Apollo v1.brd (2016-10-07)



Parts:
C1, C2: .1uF; C0603
C3, C7, C8: 10μF; C1206
C4, C5, C6: 1μF; C0603
JP1, JP2: PINHD-1X1; 1X01
JP3, JP4, JP5, JP6, JP7, JP8, JP9, JP10, JP11, JP12, JP13, JP14, JP15, JP16, JP17, JP18: PINHD-1X2; 1X02
JP19, JP20, JP21, JP22, JP23, JP24, JP25, JP26, JP27, JP28, JP29, JP30, JP31, JP32, JP33, JP34: PINHD-2X3; 2X03
Q1, Q2, Q3, Q4, Q5, Q6, Q7, Q8, Q9, Q10, Q11, Q12, Q13, Q14, Q15, Q16: DMN6140L-7; SOT-23-3
R1, R2, R3, R4, R5, R6, R7, R8, R9, R10, R11, R12, R13, R14, R15, R16, R17, R18, R19, R20: R-US_R1206; R1206
SR1, SR2: 74HC595; SO-16
SV1, SV2: MA10-1

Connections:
DATA: SR1.P$14 (DS), SV1.9
FET_1: Q1.P$2 (S), R1.1
FET_2: Q2.P$2 (S), R2.1
FET_3: Q3.P$2 (S), R3.1
FET_4: Q4.P$2 (S), R4.1
FET_5: Q5.P$2 (S), R5.1
FET_6: Q6.P$2 (S), R6.1
FET_7: Q7.P$2 (S), R7.1
FET_8: Q8.P$2 (S), R8.1
FET_9: Q9.P$2 (S), R9.1
FET_10: Q10.P$2 (S), R10.1
FET_11: Q11.P$2 (S), R11.1
FET_12: Q12.P$2 (S), R12.1
FET_13: Q13.P$2 (S), R13.1
FET_14: Q14.P$2 (S), R14.1
FET_15: Q15.P$2 (S), R15.1
FET_16: Q16.P$2 (S), R16.1
GND: C1.2, C2.2, C3.2, C4.1, C5.1, C6.1, C7.2, C8.2, Q1.P$3 (D), Q2.P$3 (D), Q3.P$3 (D), Q4.P$3 (D), Q5.P$3 (D), Q6.P$3 (D), Q7.P$3 (D), Q8.P$3 (D), Q9.P$3 (D), Q10.P$3 (D), Q11.P$3 (D), Q12.P$3 (D), Q13.P$3 (D), Q14.P$3 (D), Q15.P$3 (D), Q16.P$3 (D), R17.1, R18.1, SR1.P$8 (GND), SR2.P$8 (GND), SV1.4
LATCH_CLK: SR1.P$12 (STCP), SR2.P$12 (STCP), SV1.7
LED_1: Q1.P$1 (G), SR1.P$15 (Q0)
LED_2: Q2.P$1 (G), SR1.P$1 (Q1)
LED_3: Q3.P$1 (G), SR1.P$2 (Q2)
LED_4: Q4.P$1 (G), SR1.P$3 (Q3)
LED_5: Q5.P$1 (G), SR1.P$4 (Q4)
LED_6: Q6.P$1 (G), SR1.P$5 (Q5)
LED_7: Q7.P$1 (G), SR1.P$6 (Q6)
LED_8: Q8.P$1 (G), SR1.P$7 (Q7)
LED_9: Q9.P$1 (G), SR2.P$15 (Q0)
LED_10: Q10.P$1 (G), SR2.P$1 (Q1)
LED_11: Q11.P$1 (G), SR2.P$2 (Q2)
LED_12: Q12.P$1 (G), SR2.P$3 (Q3)
LED_13: Q13.P$1 (G), SR2.P$4 (Q4)
LED_14: Q14.P$1 (G), SR2.P$5 (Q5)
LED_15: Q15.P$1 (G), SR2.P$6 (Q6)
LED_16: Q16.P$1 (G), SR2.P$7 (Q7)
M_RESET_1: R19.1, SR1.P$10 (MR)
M_RESET_2: R20.1, SR2.P$10 (MR)
unnamed: JP3.2, R1.2
unnamed: JP4.2, R2.2
unnamed: JP5.2, R3.2
unnamed: JP6.2, R4.2
unnamed: JP7.2, R5.2
unnamed: JP8.2, R6.2
unnamed: JP9.2, R7.2
unnamed: JP10.2, R8.2
unnamed: JP11.2, R9.2
unnamed: JP12.2, R10.2
unnamed: JP13.2, R11.2
unnamed: JP14.2, R12.2
unnamed: JP15.2, R13.2
unnamed: JP16.2, R14.2
unnamed: JP17.2, R15.2
unnamed: JP18.2, R16.2
unnamed: JP3.1, JP19.3
unnamed: JP4.1, JP20.3
unnamed: JP5.1, JP21.3
unnamed: JP6.1, JP22.3
unnamed: JP7.1, JP23.3
unnamed: JP8.1, JP24.3
unnamed: JP9.1, JP25.3
unnamed: JP10.1, JP26.3
unnamed: JP11.1, JP27.3
unnamed: JP12.1, JP28.3
unnamed: JP13.1, JP29.3
unnamed: JP14.1, JP30.3
unnamed: JP15.1, JP31.3
unnamed: JP16.1, JP32.3
unnamed: JP17.1, JP33.3
unnamed: JP18.1, JP34.3
OUT_ENABLE_1: R18.2, SR1.P$13 (OE)
OUT_ENABLE_2: R17.2, SR2.P$13 (OE)
PP3V3: C1.1, C2.1, C5.2, C7.1, JP19.1, JP20.1, JP21.1, JP22.1, JP23.1, JP24.1, JP25.1, JP26.1, JP27.1, JP28.1, JP29.1, JP30.1, JP31.1, JP32.1, JP33.1, JP34.1, R19.2, R20.2, SR1.P$16 (VCC), SR2.P$16 (VCC), SV1.3
PP5V: C3.1, C4.2, JP19.4, JP20.4, JP21.4, JP22.4, JP23.4, JP24.4, JP25.4, JP26.4, JP27.4, JP28.4, JP29.4, JP30.4, JP31.4, JP32.4, JP33.4, JP34.4, SV1.2
PP12V: C6.2, C8.1, JP19.5, JP20.5, JP21.5, JP22.5, JP23.5, JP24.5, JP25.5, JP26.5, JP27.5, JP28.5, JP29.5, JP30.5, JP31.5, JP32.5, JP33.5, JP34.5, SV1.1
SERIES_CONNECT: SR1.P$9 (Q7S), SR2.P$14 (DS)
SHIFT_CLK: SR1.P$11 (SHCP), SR2.P$11 (SHCP), SV1.8



Board: 2 copper layers, 50.8 x 50.8 mm, 82 parts (17 on the bottom side), 76 nets.

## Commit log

2016-10-07 Initial upload
    [Apollo v1.brd, Apollo v1.sch, Hephaestus v1.sch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]
2016-10-09 added Dionysus incomplete schematic
    [Dionysus v1.sch]
2016-11-12 moved connector on iris
    [Iris v1.sch]
2016-11-12 updated hermes
    [Hermes v2.brd, hermes v2.brd, hermes v2.sch]
2016-11-21 Preliminary push of Hephastus V1_5. Values for specific components on A4957 chip have yet to be settled, and connectors (board-board, board-cart, board-motor) have yet to be selected. "Structure" of 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
    [Hephaestus v1_5.sch]
2016-11-21 Added the library containing (layout incomplete) components for the Hephaestus board.
2016-12-03 Schematic for Hephaestus V1_5 is essentially complete, need to select C2 and C1 values
    [Hephaestus v1_5.sch]
2017-01-14 I updated Olympus by changing the USB pins, the GPIO LEDS, and updated the Hermes, Hephaestus, and Iris pinouts and connections to the microcontroller. I also added pull down resistors on theLEDS.
    [Olympus v2.brd, Olympus v2.sch]
2017-01-21 Added golf cart master schematic
    [Golf Cart Schematic.sch]
2017-01-21 Small changes and updates to the catch-diodes and P/N
    [Hephaestus v1_5.sch]
2017-01-21 Updated NMOS/PMOS/Catch Diodes to properly specc, added voltage divider / buffer between current transducer and ADC.
    [Hephaestus v1_5.sch]
2017-01-22 fixed hermes issues
    [hermes v2.brd, hermes v2.sch]
2017-01-22 fixed more hermes things
    [hermes v2.brd, hermes v2.sch]
2017-01-28 Most recent revision; added voltage divider / buffer to make current transducers compatible with ADC input voltage.
    [Hephaestus v1_5.sch]
2017-01-28 Fixed layouts and pin ordering / connections.
    [Hephaestus v1_5.sch]
2017-02-04 Hopefully the resistors and capacitors are up to spec and I can move on.
    [Hephaestus v1_5.sch]
2017-02-17 Most recent changes (gate logic, decoupling capacitors, everything hopefully properly specced) hopefully
    [Hephaestus v1_5.sch]

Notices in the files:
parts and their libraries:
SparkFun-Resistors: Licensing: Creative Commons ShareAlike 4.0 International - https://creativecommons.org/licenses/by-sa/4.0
